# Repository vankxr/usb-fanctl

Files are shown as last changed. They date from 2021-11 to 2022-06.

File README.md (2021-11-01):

# USB Fan Controller
There are many USB fan controllers on sale, but none of them allow you to PWM 2-pin fans, as far as I am aware. This controller implements a compatible and widely supported USB serial port interface and allows you to control fans with it. It also supports 1-Wire sensors for temperature measurement.

## Authors

* **João Silva** - [vankxr](https://github.com/vankxr)

## License

The content of this repository is licensed under the [GNU General Public License v3.0](LICENSE).

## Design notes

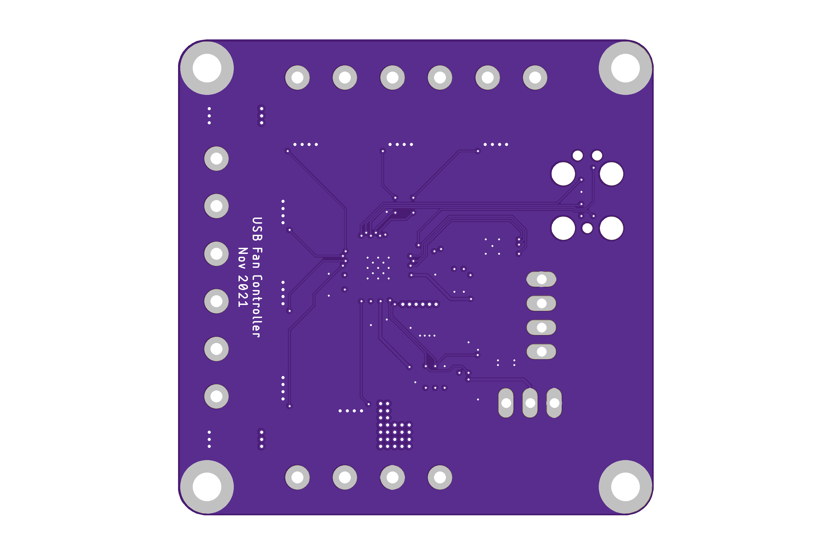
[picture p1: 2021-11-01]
pcb/usb-fanctl-bot.png

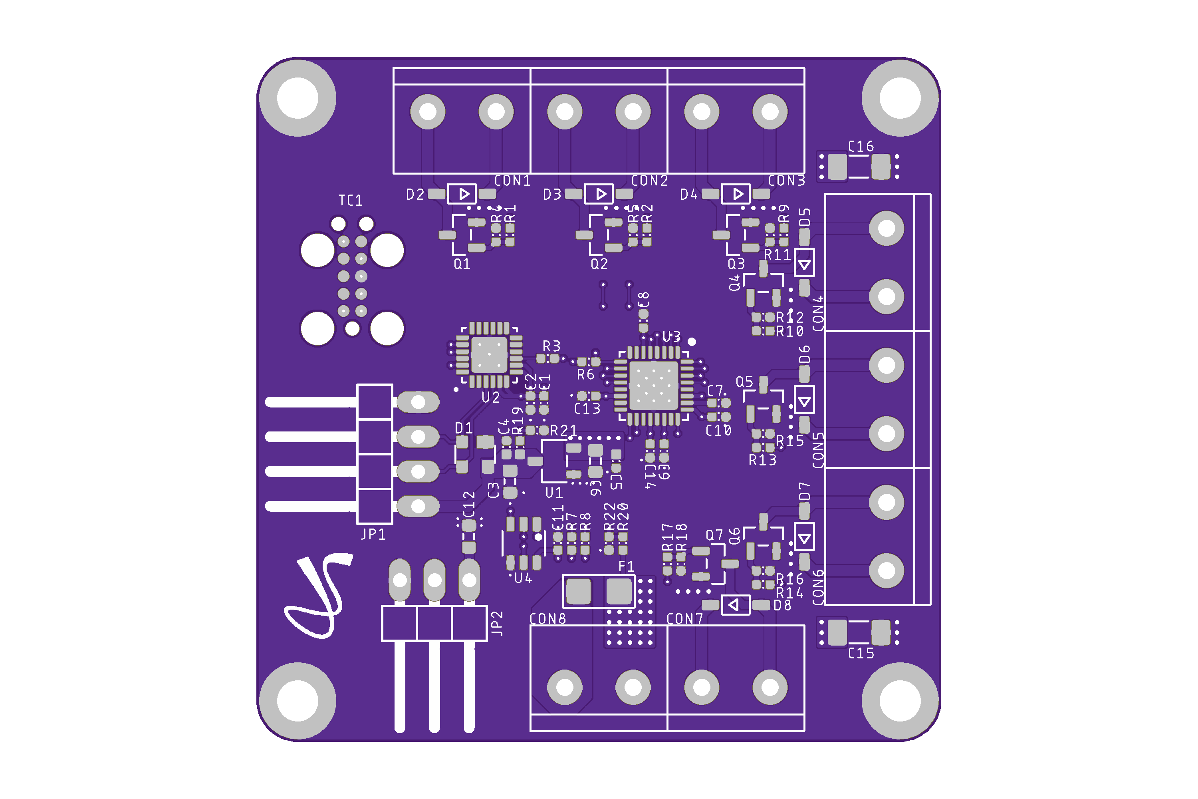
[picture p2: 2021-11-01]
pcb/usb-fanctl-top.png

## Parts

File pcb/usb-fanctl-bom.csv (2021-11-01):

Comment | Footprint | Designator
PTC 3A | PTC1206 | F1
100K Ohms | RES0402 | R20
100nF | CAP0402 | C1, C4, C5, C8, C9, C10, C11, C13, C14
10K Ohms | RES0402 | R4, R5, R6, R11, R12, R15, R16, R18, R19, R22
10uF | CAP0603 | C3, C6, C12
1K Ohms | RES0402 | R3, R7, R8
1uF | CAP0402 | C2, C7
22 Ohms | RES0402 | R1, R2, R9, R10, R13, R14, R17
22uF | CAP1206 | C15, C16
8.2K Ohms | RES0402 | R21
AO3400 | SOT23 | Q1, Q2, Q3, Q4, Q5, Q6, Q7
B0530W | SOD-123 | D2, D3, D4, D5, D6, D7, D8
CP2102N | QFN24 | U2
DS2484 | SOT23-6 | U4
EFM32PG1B100F256GM32 | QFN32_0.5P_JPG | U3
KF301-2P | KF301-2P | CON1, CON2, CON3, CON4, CON5, CON6, CON7, CON8
MCP1700-330 | SOT23 | U1
PINHD-1X3/90 | 1X03/90 | JP2
PINHD-1X4/90 | 1X04/90 | JP1
SP0503BAHT | SOT143 | D1

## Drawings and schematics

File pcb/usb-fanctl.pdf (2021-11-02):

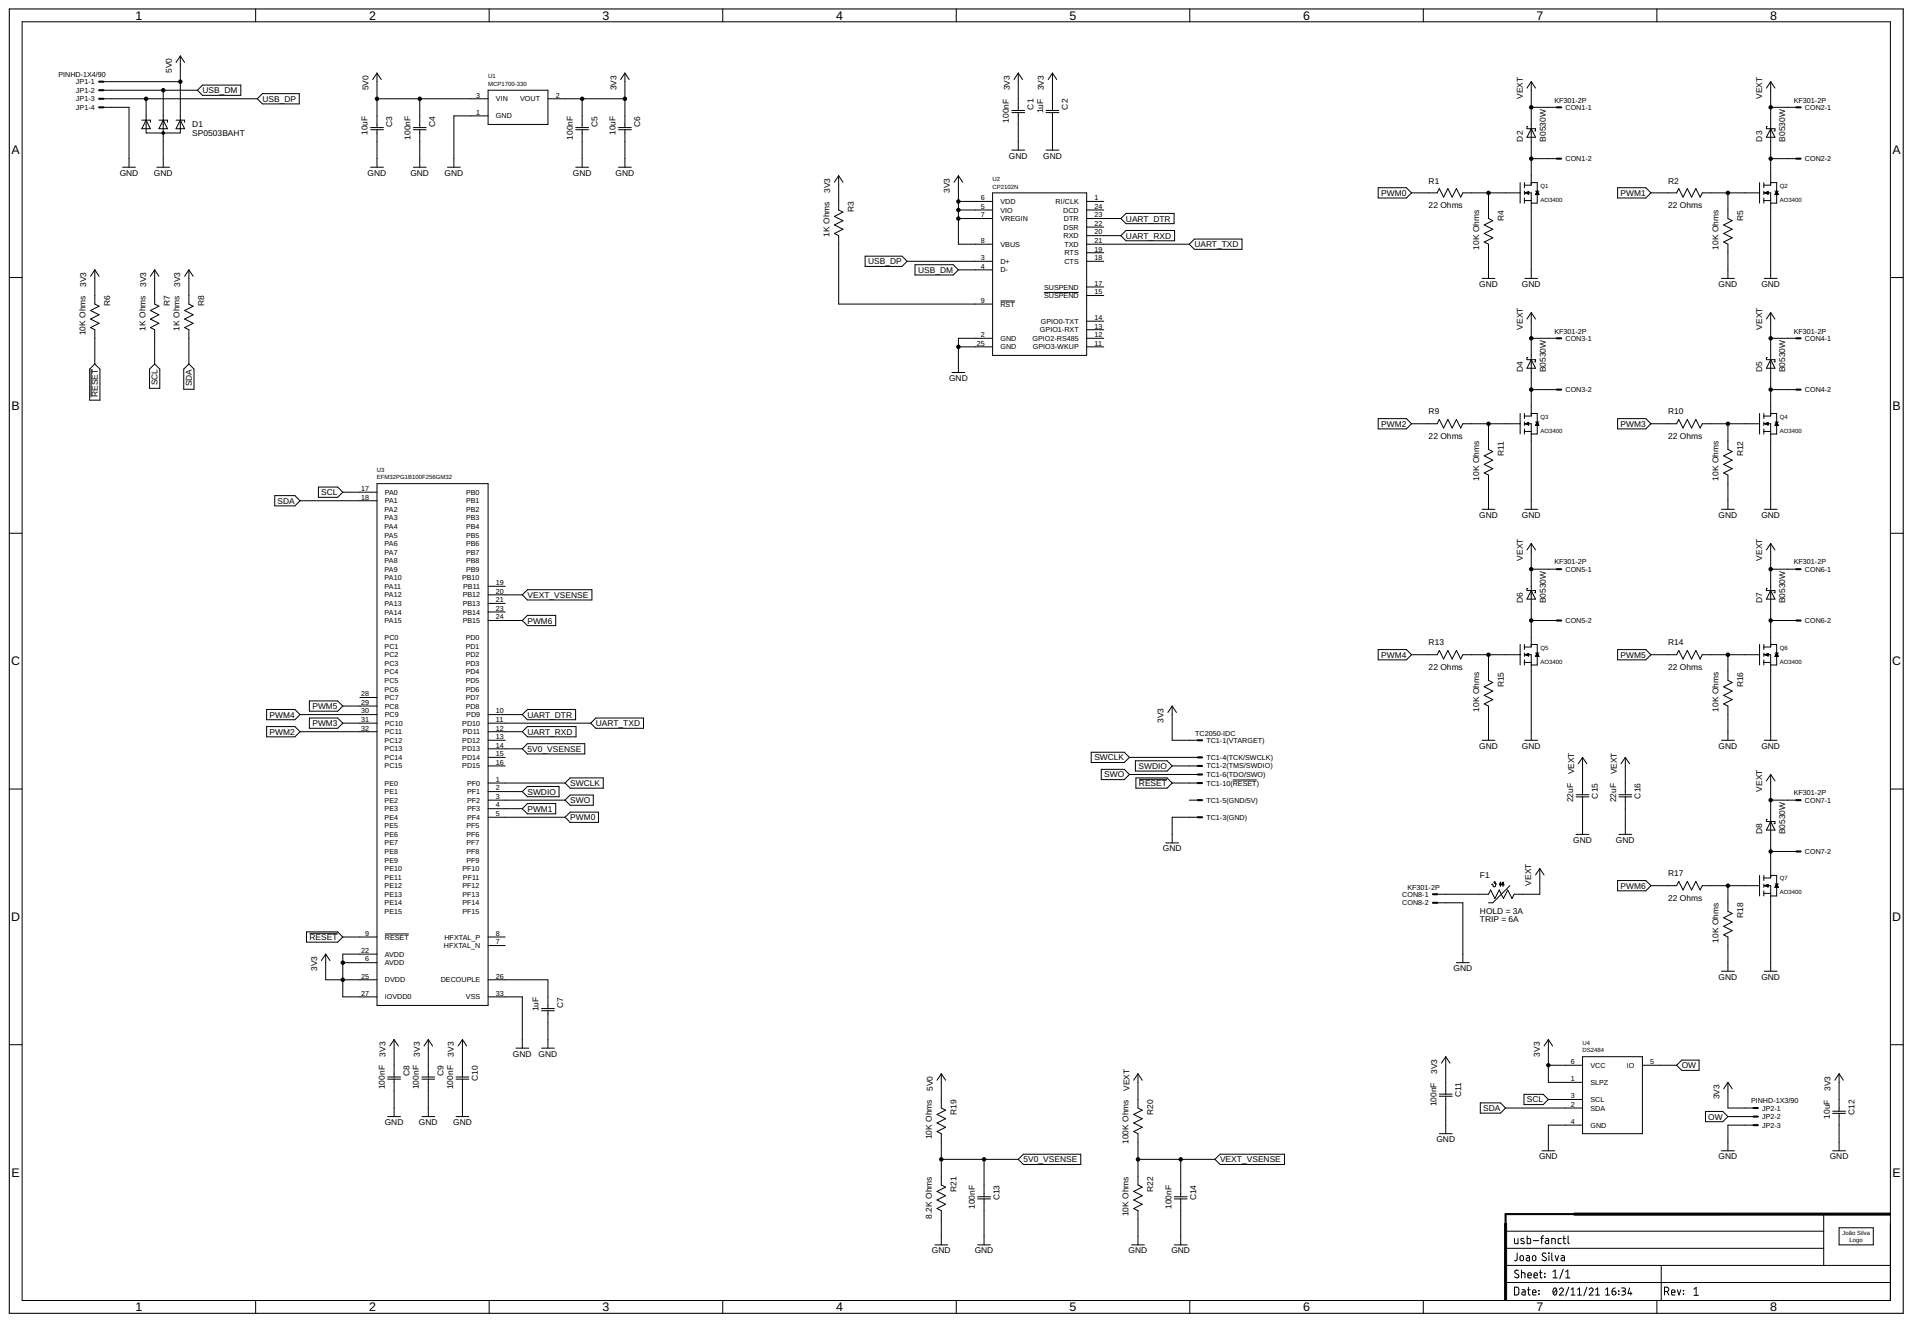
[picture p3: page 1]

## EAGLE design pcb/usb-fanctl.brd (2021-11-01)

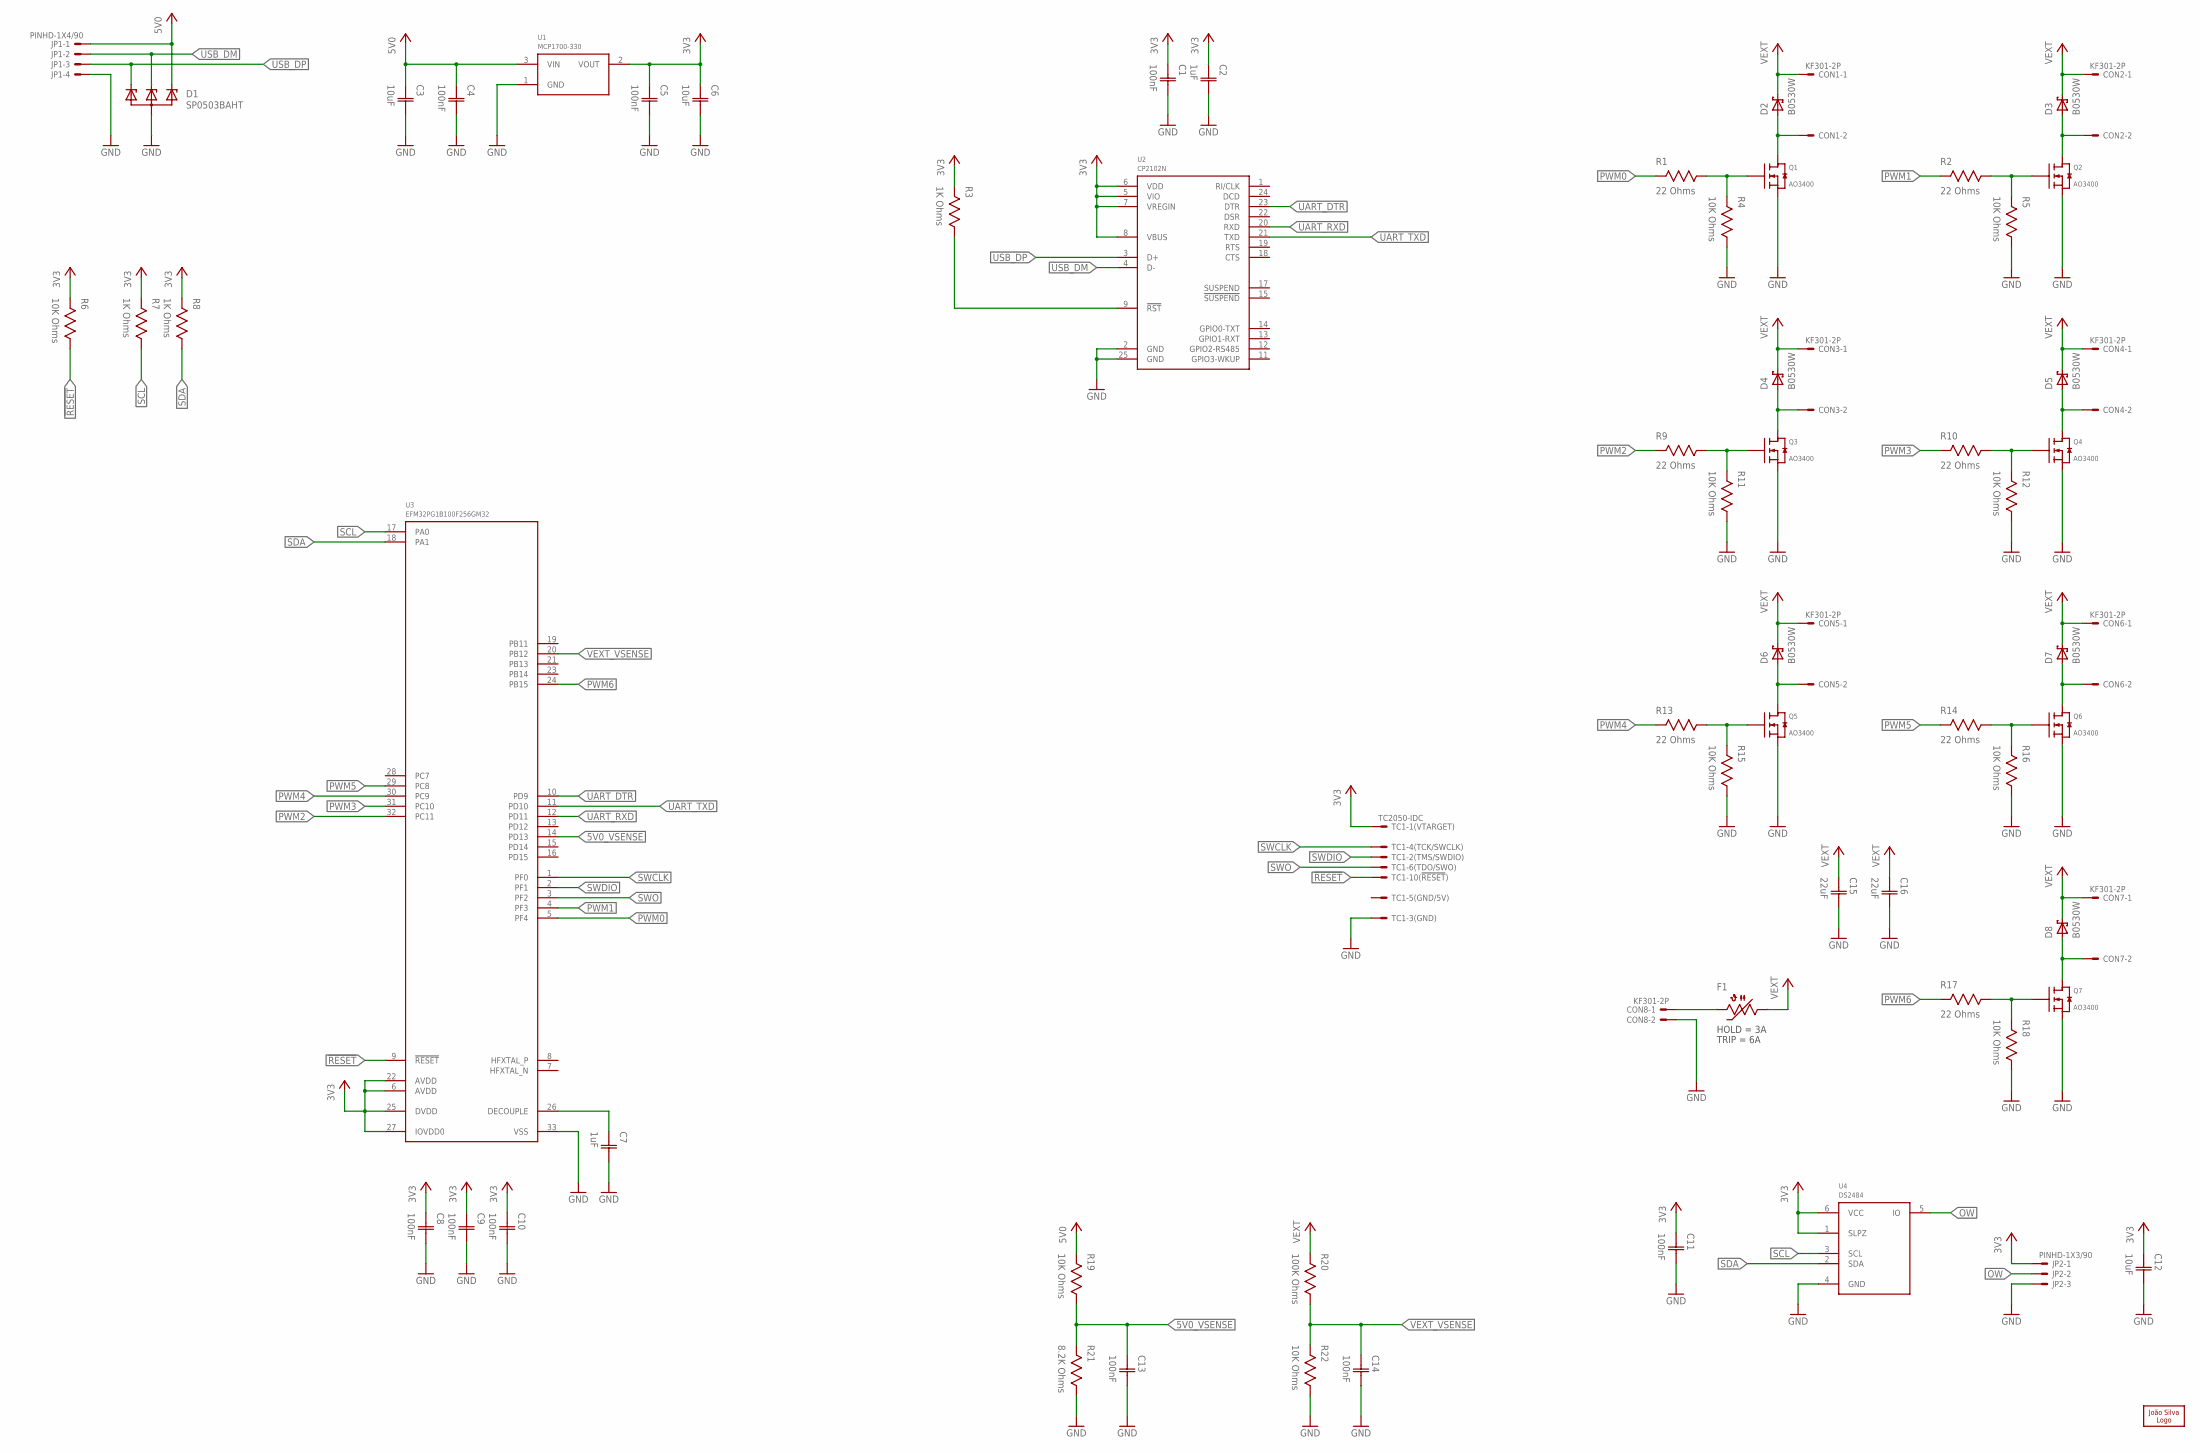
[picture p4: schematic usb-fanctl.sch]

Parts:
C1, C4, C5, C8, C9, C10, C11, C13, C14: 100nF; CAP0402
C2, C7: 1uF; CAP0402
C3, C6, C12: 10uF; CAP0603
C15, C16: 22uF; CAP1206
CON1, CON2, CON3, CON4, CON5, CON6, CON7, CON8: KF301-2P
D1: SP0503BAHT; SOT143
D2, D3, D4, D5, D6, D7, D8: B0530W; SOD-123
F1: PTC1206; 1206
JP1: PINHD-1X4/90; 1X04/90
JP2: PINHD-1X3/90; 1X03/90
LOGO1: JS-5MM; JS_5MM
Q1, Q2, Q3, Q4, Q5, Q6, Q7: AO3400; SOT23
R1, R2, R9, R10, R13, R14, R17: 22 Ohms; RES0402
R3, R7, R8: 1K Ohms; RES0402
R4, R5, R6, R11, R12, R15, R16, R18, R19, R22: 10K Ohms; RES0402
R20: 100K Ohms; RES0402
R21: 8.2K Ohms; RES0402
TC1: TC2050-IDC
U1: MCP1700-330; SOT23
U2: CP2102N; QFN24
U3: EFM32PG1B100F256GM32; QFN32_0.5P_JPG
U4: DS2484; SOT23-6

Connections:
3V3: C1.1 (C1), C2.1 (C1), C5.1 (C1), C6.1 (C1), C8.1 (C1), C9.1 (C1), C10.1 (C1), C11.1 (C1), C12.1 (C1), JP2.1, R3.2, R6.2, R7.2, R8.2, TC1.1, U1.2 (VOUT), U2.5 (VIO), U2.6 (VDD), U2.7 (VREGIN), U2.8 (VBUS), U3.6 (AVDD), U3.22 (AVDD), U3.25 (DVDD), U3.27 (IOVDD0), U4.1 (SLPZ), U4.6 (VCC)
5V0: C3.1 (C1), C4.1 (C1), D1.4 (C3), JP1.1, R19.2, U1.3 (VIN)
5V0_VSENSE: C13.1 (C1), R19.1, R21.2, U3.14 (PD13)
!RESET: R6.1, TC1.10, U3.9 (!RESET)
GND: C1.2 (C2), C2.2 (C2), C3.2 (C2), C4.2 (C2), C5.2 (C2), C6.2 (C2), C7.2 (C2), C8.2 (C2), C9.2 (C2), C10.2 (C2), C11.2 (C2), C12.2 (C2), C13.2 (C2), C14.2 (C2), C15.2 (C2), C16.2 (C2), CON8.2, D1.1 (A), JP1.4, JP2.3, Q1.2 (S), Q2.2 (S), Q3.2 (S), Q4.2 (S), Q5.2 (S), Q6.2 (S), Q7.2 (S), R4.1, R5.1, R11.1, R12.1, R15.1, R16.1, R18.1, R21.1, R22.1, TC1.3, U1.1 (GND), U2.2 (GND), U2.25 (GND), U3.33 (VSS), U4.4 (GND)
unnamed: Q2.1 (G), R2.1, R5.2
unnamed: CON2.2, D3.A, Q2.3 (D)
unnamed: Q4.1 (G), R10.1, R12.2
unnamed: CON4.2, D5.A, Q4.3 (D)
unnamed: Q6.1 (G), R14.1, R16.2
unnamed: CON6.2, D7.A, Q6.3 (D)
unnamed: Q7.1 (G), R17.1, R18.2
unnamed: CON7.2, D8.A, Q7.3 (D)
unnamed: Q1.1 (G), R1.1, R4.2
unnamed: CON1.2, D2.A, Q1.3 (D)
unnamed: Q3.1 (G), R9.1, R11.2
unnamed: CON3.2, D4.A, Q3.3 (D)
unnamed: Q5.1 (G), R13.1, R15.2
unnamed: CON5.2, D6.A, Q5.3 (D)
unnamed: C7.1 (C1), U3.26 (DECOUPLE)
unnamed: R3.1, U2.9 (!RST)
OW: JP2.2, U4.5 (IO)
PWM0: R1.2, U3.5 (PF4)
PWM1: R2.2, U3.4 (PF3)
PWM2: R9.2, U3.32 (PC11)
PWM3: R10.2, U3.31 (PC10)
PWM4: R13.2, U3.30 (PC9)
PWM5: R14.2, U3.29 (PC8)
PWM6: R17.2, U3.24 (PB15)
SCL: R7.1, U3.17 (PA0), U4.3 (SCL)
SDA: R8.1, U3.18 (PA1), U4.2 (SDA)
SWCLK: TC1.4, U3.1 (PF0)
SWDIO: TC1.2, U3.2 (PF1)
SWO: TC1.6, U3.3 (PF2)
UART_DTR: U2.23 (DTR), U3.10 (PD9)
UART_RXD: U2.20 (RXD), U3.12 (PD11)
UART_TXD: U2.21 (TXD), U3.11 (PD10)
USB_DM: D1.3 (C2), JP1.2, U2.4 (D-)
USB_DP: D1.2 (C1), JP1.3, U2.3 (D+)
VEXT: C15.1 (C1), C16.1 (C1), CON1.1, CON2.1, CON3.1, CON4.1, CON5.1, CON6.1, CON7.1, D2.C, D3.C, D4.C, D5.C, D6.C, D7.C, D8.C, F1.1, R20.2
VEXT_UNFUSED: CON8.1, F1.2
VEXT_VSENSE: C14.1 (C1), R20.1, R22.2, U3.20 (PB12)

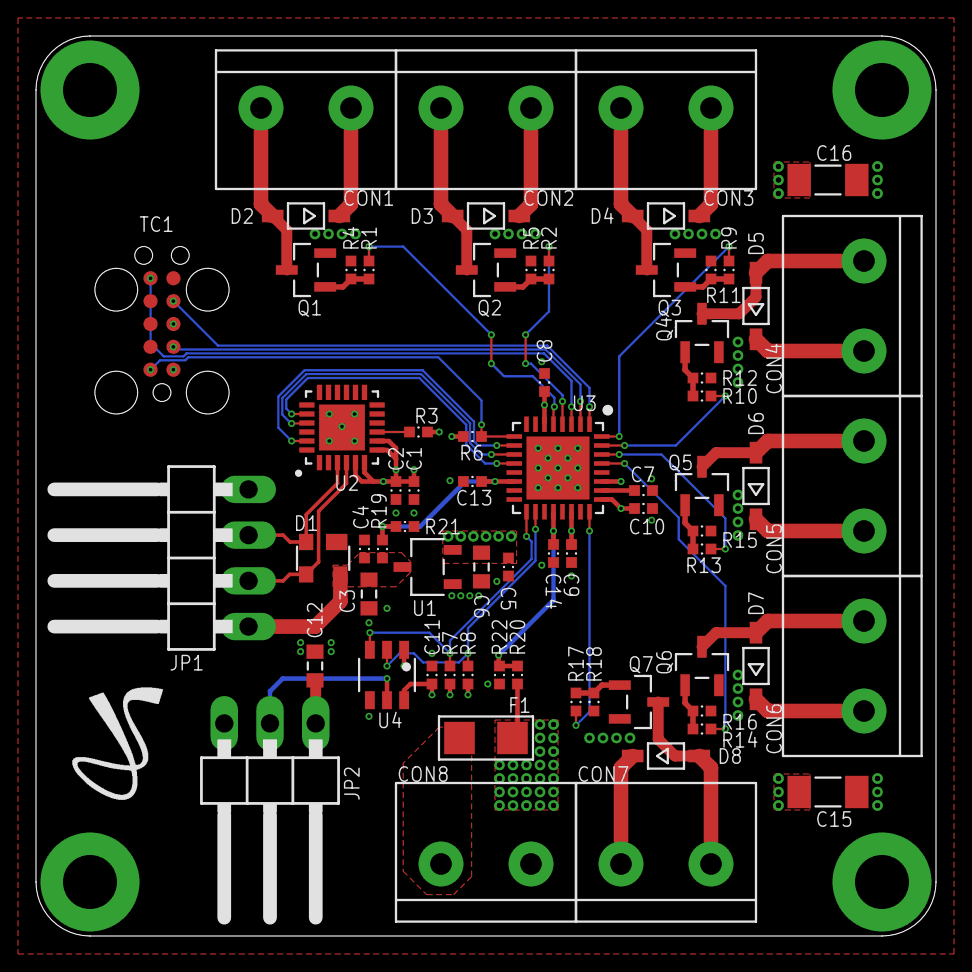
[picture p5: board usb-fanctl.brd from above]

Board: 4 copper layers, 50.0 x 50.0 mm, 70 parts (0 on the bottom side), 42 nets.

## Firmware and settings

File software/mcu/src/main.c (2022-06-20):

#include <em_device.h>
#include <stdlib.h>
#include <math.h>
#include "debug_macros.h"
#include "utils.h"
#include "nvic.h"
#include "atomic.h"
#include "systick.h"
#include "rmu.h"
#include "emu.h"
#include "cmu.h"
#include "gpio.h"
#include "dbg.h"
#include "msc.h"
#include "rtcc.h"
#include "adc.h"
#include "crc.h"
#include "usart.h"
#include "i2c.h"
#include "wdog.h"

// Structs
typedef struct __attribute__((__packed__))
{
    uint16_t usMagic;
    uint8_t ubCommand;
    uint8_t ubPayloadSize;
} usart_cmd_header_t;

typedef struct __attribute__((__packed__))
{
    uint8_t ubChannel;
    float fDutyCycle;
} usart_cmd_set_dc_t;
typedef struct __attribute__((__packed__))
{
    uint8_t ubChannel;
    float fDutyCycle;
} usart_cmd_get_dc_t;
typedef struct __attribute__((__packed__))
{
    float fFreq;
} usart_cmd_set_freq_t;
typedef struct __attribute__((__packed__))
{
    float fFreq;
} usart_cmd_get_freq_t;
typedef struct __attribute__((__packed__))
{
    uint8_t ubChannel;
    float fVoltage;
} usart_cmd_get_voltage_t;
typedef struct __attribute__((__packed__))
{
    uint8_t ubChannel;
    float fTemperature;
} usart_cmd_get_temp_t;
typedef struct __attribute__((__packed__))
{
    uint32_t ulUID[2];
} usart_cmd_get_uid_t;
typedef struct __attribute__((__packed__))
{
    uint16_t usVersion;
    char szDate[12];
    char szTime[9];
} usart_cmd_get_sw_info_t;

// Defines
#define TIMER_PWM_MIN_FREQ_HZ   500
#define TIMER_PWM_MAX_FREQ_HZ   1600000
#define TIMER_PWM_DEF_FREQ_HZ   25000

#define USART_HEADER_MAGIC      0xFAC7

#define USART_CMD_SET_DC        0x01
#define USART_CMD_GET_DC        0x02
#define USART_CMD_GET_VOLTAGE   0x03
#define USART_CMD_GET_TEMP      0x04
#define USART_CMD_SET_FREQ      0x05
#define USART_CMD_GET_FREQ      0x06
#define USART_CMD_ERROR         0xE0
#define USART_CMD_GET_UID       0xF0
#define USART_CMD_GET_SW_INFO   0xF1
#define USART_CMD_RESET_BL      0xFE
#define USART_CMD_RESET_APP     0xFF

#define USART_VOLTAGE_AVDD      0
#define USART_VOLTAGE_DVDD      1
#define USART_VOLTAGE_IOVDD     2
#define USART_VOLTAGE_CORE      3
#define USART_VOLTAGE_5V0       4
#define USART_VOLTAGE_VEXT      5

#define USART_TEMP_EMU          0
#define USART_TEMP_ADC          1

// Forward declarations
static void reset() __attribute__((noreturn));
static void sleep();

static uint32_t get_free_ram();

static void get_device_name(char *pszDeviceName, uint32_t ulDeviceNameSize);
static uint16_t get_device_revision();

static void wdog_warning_isr();

static void init_timers();
static void set_freq(float fFreq);
static float get_freq();
static void set_channel_dc(uint8_t ubChannel, float fDuty);
static float get_channel_dc(uint8_t ubChannel);

// Variables

// ISRs

// Functions
void reset()
{
    SCB->AIRCR = 0x05FA0000 | _VAL2FLD(SCB_AIRCR_SYSRESETREQ, 1);

    while(1);
}
void sleep()
{
    rtcc_set_alarm(rtcc_get_time() + 5);

    SCB->SCR |= SCB_SCR_SLEEPDEEP_Msk; // Configure Deep Sleep (EM2/3)

    ATOMIC_BLOCK(ATOMIC_RESTORESTATE)
    {
        IRQ_CLEAR(RTCC_IRQn);

        __DMB(); // Wait for all memory transactions to finish before memory access
        __DSB(); // Wait for all memory transactions to finish before executing instructions
        __ISB(); // Wait for all memory transactions to finish before fetching instructions
        __SEV(); // Set the event flag to ensure the next WFE will be a NOP
        __WFE(); // NOP and clear the event flag
        __WFE(); // Wait for event
        __NOP(); // Prevent debugger crashes

        cmu_init();
        cmu_update_clocks();
    }
}

uint32_t get_free_ram()
{
    ATOMIC_BLOCK(ATOMIC_RESTORESTATE)
    {
        extern void *_sbrk(int);

        void *pCurrentHeap = _sbrk(1);

        if(!pCurrentHeap)
            return 0;

        uint32_t ulFreeRAM = (uint32_t)__get_MSP() - (uint32_t)pCurrentHeap;

        _sbrk(-1);

        return ulFreeRAM;
    }
}

void get_device_name(char *pszDeviceName, uint32_t ulDeviceNameSize)
{
    uint8_t ubFamily = (DEVINFO->PART & _DEVINFO_PART_DEVICE_FAMILY_MASK) >> _DEVINFO_PART_DEVICE_FAMILY_SHIFT;
    const char* szFamily = "?";

    switch(ubFamily)
    {
        case 0x10: szFamily = "EFR32MG1P";  break;
        case 0x11: szFamily = "EFR32MG1B";  break;
        case 0x12: szFamily = "EFR32MG1V";  break;
        case 0x13: szFamily = "EFR32BG1P";  break;
        case 0x14: szFamily = "EFR32BG1B";  break;
        case 0x15: szFamily = "EFR32BG1V";  break;
        case 0x19: szFamily = "EFR32FG1P";  break;
        case 0x1A: szFamily = "EFR32FG1B";  break;
        case 0x1B: szFamily = "EFR32FG1V";  break;
        case 0x1C: szFamily = "EFR32MG12P"; break;
        case 0x1D: szFamily = "EFR32MG12B"; break;
        case 0x1E: szFamily = "EFR32MG12V"; break;
        case 0x1F: szFamily = "EFR32BG12P"; break;
        case 0x20: szFamily = "EFR32BG12B"; break;
        case 0x21: szFamily = "EFR32BG12V"; break;
        case 0x25: szFamily = "EFR32FG12P"; break;
        case 0x26: szFamily = "EFR32FG12B"; break;
        case 0x27: szFamily = "EFR32FG12V"; break;
        case 0x28: szFamily = "EFR32MG13P"; break;
        case 0x29: szFamily = "EFR32MG13B"; break;
        case 0x2A: szFamily = "EFR32MG13V"; break;
        case 0x2B: szFamily = "EFR32BG13P"; break;
        case 0x2C: szFamily = "EFR32BG13B"; break;
        case 0x2D: szFamily = "EFR32BG13V"; break;
        case 0x2E: szFamily = "EFR32ZG13P"; break;
        case 0x31: szFamily = "EFR32FG13P"; break;
        case 0x32: szFamily = "EFR32FG13B"; break;
        case 0x33: szFamily = "EFR32FG13V"; break;
        case 0x34: szFamily = "EFR32MG14P"; break;
        case 0x35: szFamily = "EFR32MG14B"; break;
        case 0x36: szFamily = "EFR32MG14V"; break;
        case 0x37: szFamily = "EFR32BG14P"; break;
        case 0x38: szFamily = "EFR32BG14B"; break;
        case 0x39: szFamily = "EFR32BG14V"; break;
        case 0x3A: szFamily = "EFR32ZG14P"; break;
        case 0x3D: szFamily = "EFR32FG14P"; break;
        case 0x3E: szFamily = "EFR32FG14B"; break;
        case 0x3F: szFamily = "EFR32FG14V"; break;
        case 0x47: szFamily = "EFM32G";     break;
        case 0x48: szFamily = "EFM32GG";    break;
        case 0x49: szFamily = "EFM32TG";    break;
        case 0x4A: szFamily = "EFM32LG";    break;
        case 0x4B: szFamily = "EFM32WG";    break;
        case 0x4C: szFamily = "EFM32ZG";    break;
        case 0x4D: szFamily = "EFM32HG";    break;
        case 0x51: szFamily = "EFM32PG1B";  break;
        case 0x53: szFamily = "EFM32JG1B";  break;
        case 0x55: szFamily = "EFM32PG12B"; break;
        case 0x57: szFamily = "EFM32JG12B"; break;
        case 0x64: szFamily = "EFM32GG11B"; break;
        case 0x67: szFamily = "EFM32TG11B"; break;
        case 0x6A: szFamily = "EFM32GG12B"; break;
        case 0x78: szFamily = "EZR32LG";    break;
        case 0x79: szFamily = "EZR32WG";    break;
        case 0x7A: szFamily = "EZR32HG";    break;
    }

    uint8_t ubPackage = (DEVINFO->MEMINFO & _DEVINFO_MEMINFO_PKGTYPE_MASK) >> _DEVINFO_MEMINFO_PKGTYPE_SHIFT;
    char cPackage = '?';

    if(ubPackage == 74)
        cPackage = '?';
    else if(ubPackage == 76)
        cPackage = 'L';
    else if(ubPackage == 77)
        cPackage = 'M';
    else if(ubPackage == 81)
        cPackage = 'Q';

    uint8_t ubTempGrade = (DEVINFO->MEMINFO & _DEVINFO_MEMINFO_TEMPGRADE_MASK) >> _DEVINFO_MEMINFO_TEMPGRADE_SHIFT;
    char cTempGrade = '?';

    if(ubTempGrade == 0)
        cTempGrade = 'G';
    else if(ubTempGrade == 1)
        cTempGrade = 'I';
    else if(ubTempGrade == 2)
        cTempGrade = '?';
    else if(ubTempGrade == 3)
        cTempGrade = '?';

    uint16_t usPartNumber = (DEVINFO->PART & _DEVINFO_PART_DEVICE_NUMBER_MASK) >> _DEVINFO_PART_DEVICE_NUMBER_SHIFT;
    uint8_t ubPinCount = (DEVINFO->MEMINFO & _DEVINFO_MEMINFO_PINCOUNT_MASK) >> _DEVINFO_MEMINFO_PINCOUNT_SHIFT;

    snprintf(pszDeviceName, ulDeviceNameSize, "%s%huF%hu%c%c%hhu", szFamily, usPartNumber, FLASH_SIZE >> 10, cTempGrade, cPackage, ubPinCount);
}
uint16_t get_device_revision()
{
    uint16_t usRevision;

    /* CHIP MAJOR bit [3:0]. */
    usRevision = ((ROMTABLE->PID0 & _ROMTABLE_PID0_REVMAJOR_MASK) >> _ROMTABLE_PID0_REVMAJOR_SHIFT) << 8;
    /* CHIP MINOR bit [7:4]. */
    usRevision |= ((ROMTABLE->PID2 & _ROMTABLE_PID2_REVMINORMSB_MASK) >> _ROMTABLE_PID2_REVMINORMSB_SHIFT) << 4;
    /* CHIP MINOR bit [3:0]. */
    usRevision |= (ROMTABLE->PID3 & _ROMTABLE_PID3_REVMINORLSB_MASK) >> _ROMTABLE_PID3_REVMINORLSB_SHIFT;

    return usRevision;
}

void wdog_warning_isr()
{
    DBGPRINTLN_CTX("Watchdog warning!");
}

void init_timers()
{
    // Timer 0
    cmu_hfper0_clock_gate(CMU_HFPERCLKEN0_TIMER0, 1);

    TIMER0->CTRL = TIMER_CTRL_RSSCOIST | TIMER_CTRL_PRESC_DIV1 | TIMER_CTRL_CLKSEL_PRESCHFPERCLK | TIMER_CTRL_FALLA_NONE | TIMER_CTRL_RISEA_NONE | TIMER_CTRL_MODE_UP;
    TIMER0->TOP = HFPER_CLOCK_FREQ / TIMER_PWM_DEF_FREQ_HZ - 1;
    TIMER0->CNT = 0x0000;

    TIMER0->CC[0].CTRL = TIMER_CC_CTRL_PRSCONF_LEVEL | TIMER_CC_CTRL_CUFOA_NONE | TIMER_CC_CTRL_COFOA_SET | TIMER_CC_CTRL_CMOA_CLEAR | TIMER_CC_CTRL_MODE_PWM;
    TIMER0->CC[0].CCV = 0x0000;

    TIMER0->CC[1].CTRL = TIMER_CC_CTRL_PRSCONF_LEVEL | TIMER_CC_CTRL_CUFOA_NONE | TIMER_CC_CTRL_COFOA_SET | TIMER_CC_CTRL_CMOA_CLEAR | TIMER_CC_CTRL_MODE_PWM;
    TIMER0->CC[1].CCV = 0x0000;

    TIMER0->CC[2].CTRL = TIMER_CC_CTRL_PRSCONF_LEVEL | TIMER_CC_CTRL_CUFOA_NONE | TIMER_CC_CTRL_COFOA_SET | TIMER_CC_CTRL_CMOA_CLEAR | TIMER_CC_CTRL_MODE_PWM;
    TIMER0->CC[2].CCV = 0x0000;

    TIMER0->ROUTELOC0 = TIMER_ROUTELOC0_CC0LOC_LOC28 | TIMER_ROUTELOC0_CC1LOC_LOC26 | TIMER_ROUTELOC0_CC2LOC_LOC14;
    TIMER0->ROUTEPEN |= TIMER_ROUTEPEN_CC0PEN | TIMER_ROUTEPEN_CC1PEN | TIMER_ROUTEPEN_CC2PEN;

    // Timer 1
    cmu_hfper0_clock_gate(CMU_HFPERCLKEN0_TIMER1, 1);

    TIMER1->CTRL = TIMER_CTRL_RSSCOIST | TIMER_CTRL_PRESC_DIV1 | TIMER_CTRL_CLKSEL_PRESCHFPERCLK | TIMER_CTRL_FALLA_NONE | TIMER_CTRL_RISEA_NONE | TIMER_CTRL_MODE_UP;
    TIMER1->TOP = HFPER_CLOCK_FREQ / TIMER_PWM_DEF_FREQ_HZ - 1;
    TIMER1->CNT = 0x0000;

    TIMER1->CC[0].CTRL = TIMER_CC_CTRL_PRSCONF_LEVEL | TIMER_CC_CTRL_CUFOA_NONE | TIMER_CC_CTRL_COFOA_SET | TIMER_CC_CTRL_CMOA_CLEAR | TIMER_CC_CTRL_MODE_PWM;
    TIMER1->CC[0].CCV = 0x0000;

    TIMER1->CC[1].CTRL = TIMER_CC_CTRL_PRSCONF_LEVEL | TIMER_CC_CTRL_CUFOA_NONE | TIMER_CC_CTRL_COFOA_SET | TIMER_CC_CTRL_CMOA_CLEAR | TIMER_CC_CTRL_MODE_PWM;
    TIMER1->CC[1].CCV = 0x0000;

    TIMER1->CC[2].CTRL = TIMER_CC_CTRL_PRSCONF_LEVEL | TIMER_CC_CTRL_CUFOA_NONE | TIMER_CC_CTRL_COFOA_SET | TIMER_CC_CTRL_CMOA_CLEAR | TIMER_CC_CTRL_MODE_PWM;
    TIMER1->CC[2].CCV = 0x0000;

    TIMER1->CC[3].CTRL = TIMER_CC_CTRL_PRSCONF_LEVEL | TIMER_CC_CTRL_CUFOA_NONE | TIMER_CC_CTRL_COFOA_SET | TIMER_CC_CTRL_CMOA_CLEAR | TIMER_CC_CTRL_MODE_PWM;
    TIMER1->CC[3].CCV = 0x0000;

    TIMER1->ROUTELOC0 = TIMER_ROUTELOC0_CC0LOC_LOC15 | TIMER_ROUTELOC0_CC1LOC_LOC13 | TIMER_ROUTELOC0_CC2LOC_LOC11 | TIMER_ROUTELOC0_CC3LOC_LOC7;
    TIMER1->ROUTEPEN |= TIMER_ROUTEPEN_CC0PEN | TIMER_ROUTEPEN_CC1PEN | TIMER_ROUTEPEN_CC2PEN | TIMER_ROUTEPEN_CC3PEN;

    // Start both timers
    TIMER0->CMD = TIMER_CMD_START;
    TIMER1->CMD = TIMER_CMD_START;
}
void set_freq(float fFreq)
{
    if(fFreq < TIMER_PWM_MIN_FREQ_HZ)
        return;

    if(fFreq > TIMER_PWM_MAX_FREQ_HZ)
        return;

    float fDutyBackup[7];

    for(uint8_t i = 0; i < 7; i++)
    {
        fDutyBackup[i] = get_channel_dc(i);

        set_channel_dc(i, 0.f);
    }

    TIMER0->TOPB = HFPER_CLOCK_FREQ / fFreq - 1;
    TIMER1->TOPB = HFPER_CLOCK_FREQ / fFreq - 1;

    for(uint8_t i = 0; i < 7; i++)
        set_channel_dc(i, fDutyBackup[i]);
}
float get_freq()
{
    return (float)HFPER_CLOCK_FREQ / (TIMER0->TOP + 1);
}
void set_channel_dc(uint8_t ubChannel, float fDuty)
{
    if(ubChannel > 6)
        return;

    if(fDuty < 0 || fDuty > 1)
        return;

    if(ubChannel > 2)
        TIMER1->CC[ubChannel - 3].CCVB = (uint16_t)(fDuty * TIMER1->TOP);
    else
        TIMER0->CC[ubChannel].CCVB = (uint16_t)(fDuty * TIMER0->TOP);
}
float get_channel_dc(uint8_t ubChannel)
{
    if(ubChannel > 6)
        return 0.f;

    if(ubChannel > 2)
        return (float)TIMER1->CC[ubChannel - 3].CCV / TIMER1->TOP;
    else
        return (float)TIMER0->CC[ubChannel].CCV / TIMER0->TOP;
}
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
int main()
{
    init_timers();

    while(1)
    {
        wdog_feed();

        static uint64_t ullLastUSARTChange = 0;
        static uint32_t ulLastUSARTAvailable = 0;

        if(usart0_available() != ulLastUSARTAvailable)
        {
            ulLastUSARTAvailable = usart0_available();
            ullLastUSARTChange = g_ullSystemTick;
        }

        if(ulLastUSARTAvailable != 0 && g_ullSystemTick - ullLastUSARTChange > 2000)
        {
            DBGPRINTLN_CTX("Clearing USART buffer...");

            usart0_flush();
        }

        if(usart0_available() >= sizeof(usart_cmd_header_t))
        {
            usart_cmd_header_t xHeader;

            DBGPRINTLN_CTX("Reading header...");
            usart0_read((uint8_t *)&xHeader, sizeof(usart_cmd_header_t));

            DBGPRINTLN_CTX("Header [M %04X] [C %02X] [S %02X]", xHeader.usMagic, xHeader.ubCommand, xHeader.ubPayloadSize);

            if(xHeader.usMagic != USART_HEADER_MAGIC)
            {
                DBGPRINTLN_CTX("Invalid magic!");

                continue;
            }

            switch(xHeader.ubCommand)
            {
                case USART_CMD_SET_DC:
                {
                    if(xHeader.ubPayloadSize != sizeof(usart_cmd_set_dc_t))
                    {
                        DBGPRINTLN_CTX("Invalid payload size!");

                        xHeader.ubCommand = USART_CMD_ERROR;
                        xHeader.ubPayloadSize = 0;
                        usart0_write((uint8_t *)&xHeader, sizeof(usart_cmd_header_t));

                        break;
                    }

                    if(usart0_available() < xHeader.ubPayloadSize)
                    {
                        DBGPRINTLN_CTX("Not enough data, waiting...");

                        uint64_t ullStartTick = g_ullSystemTick;

                        while(usart0_available() < xHeader.ubPayloadSize && g_ullSystemTick - ullStartTick <= 500);

                        if(usart0_available() < xHeader.ubPayloadSize)
                        {
                            DBGPRINTLN_CTX("Timed out waiting for payload!");

                            xHeader.ubCommand = USART_CMD_ERROR;
                            xHeader.ubPayloadSize = 0;
                            usart0_write((uint8_t *)&xHeader, sizeof(usart_cmd_header_t));

                            break;
                        }
                    }

                    usart_cmd_set_dc_t xPayload;

                    DBGPRINTLN_CTX("Reading payload...");
                    usart0_read((uint8_t *)&xPayload, xHeader.ubPayloadSize);

                    DBGPRINTLN_CTX("USART_CMD_SET_DC [C %hhu] [D %.6f]", xPayload.ubChannel, xPayload.fDutyCycle);

                    if(xPayload.ubChannel > 6)
                    {
                        DBGPRINTLN_CTX("Invalid channel!");

                        xHeader.ubCommand = USART_CMD_ERROR;
                        xHeader.ubPayloadSize = 0;
                        usart0_write((uint8_t *)&xHeader, sizeof(usart_cmd_header_t));

                        break;
                    }

                    if(xPayload.fDutyCycle < 0.0f || xPayload.fDutyCycle > 1.0f)
                    {
                        DBGPRINTLN_CTX("Invalid duty cycle!");

                        xHeader.ubCommand = USART_CMD_ERROR;
                        xHeader.ubPayloadSize = 0;
                        usart0_write((uint8_t *)&xHeader, sizeof(usart_cmd_header_t));

                        break;
                    }

                    set_channel_dc(xPayload.ubChannel, xPayload.fDutyCycle);

                    xHeader.ubPayloadSize = 0;
                    usart0_write((uint8_t *)&xHeader, sizeof(usart_cmd_header_t));
                }
                break;
                case USART_CMD_GET_DC:
                {
                    if(xHeader.ubPayloadSize != sizeof(usart_cmd_get_dc_t))
                    {
                        DBGPRINTLN_CTX("Invalid payload size!");

                        xHeader.ubCommand = USART_CMD_ERROR;
                        xHeader.ubPayloadSize = 0;
                        usart0_write((uint8_t *)&xHeader, sizeof(usart_cmd_header_t));

                        break;
                    }

                    if(usart0_available() < xHeader.ubPayloadSize)
                    {
                        DBGPRINTLN_CTX("Not enough data, waiting...");

                        uint64_t ullStartTick = g_ullSystemTick;

                        while(usart0_available() < xHeader.ubPayloadSize && g_ullSystemTick - ullStartTick <= 500);

                        if(usart0_available() < xHeader.ubPayloadSize)
                        {
                            DBGPRINTLN_CTX("Timed out waiting for payload!");

                            xHeader.ubCommand = USART_CMD_ERROR;
                            xHeader.ubPayloadSize = 0;
                            usart0_write((uint8_t *)&xHeader, sizeof(usart_cmd_header_t));

                            break;
                        }
                    }

                    usart_cmd_get_dc_t xPayload;

                    DBGPRINTLN_CTX("Reading payload...");
                    usart0_read((uint8_t *)&xPayload, xHeader.ubPayloadSize);

                    DBGPRINTLN_CTX("USART_CMD_GET_DC [C %hhu]", xPayload.ubChannel);

                    if(xPayload.ubChannel > 6)
                    {
                        DBGPRINTLN_CTX("Invalid channel!");

                        xHeader.ubCommand = USART_CMD_ERROR;
                        xHeader.ubPayloadSize = 0;
                        usart0_write((uint8_t *)&xHeader, sizeof(usart_cmd_header_t));

                        break;
                    }

                    xPayload.fDutyCycle = get_channel_dc(xPayload.ubChannel);

                    usart0_write((uint8_t *)&xHeader, sizeof(usart_cmd_header_t));
                    usart0_write((uint8_t *)&xPayload, sizeof(usart_cmd_get_dc_t));
                }
                break;
                case USART_CMD_GET_VOLTAGE:
                {
                    if(xHeader.ubPayloadSize != sizeof(usart_cmd_get_voltage_t))
                    {
                        DBGPRINTLN_CTX("Invalid payload size!");

                        xHeader.ubCommand = USART_CMD_ERROR;
                        xHeader.ubPayloadSize = 0;
                        usart0_write((uint8_t *)&xHeader, sizeof(usart_cmd_header_t));

                        break;
                    }

                    if(usart0_available() < xHeader.ubPayloadSize)
                    {
                        DBGPRINTLN_CTX("Not enough data, waiting...");

                        uint64_t ullStartTick = g_ullSystemTick;

                        while(usart0_available() < xHeader.ubPayloadSize && g_ullSystemTick - ullStartTick <= 500);

                        if(usart0_available() < xHeader.ubPayloadSize)
                        {
                            DBGPRINTLN_CTX("Timed out waiting for payload!");

                            xHeader.ubCommand = USART_CMD_ERROR;
                            xHeader.ubPayloadSize = 0;
                            usart0_write((uint8_t *)&xHeader, sizeof(usart_cmd_header_t));

                            break;
                        }
                    }

                    usart_cmd_get_voltage_t xPayload;

                    DBGPRINTLN_CTX("Reading payload...");
                    usart0_read((uint8_t *)&xPayload, xHeader.ubPayloadSize);

                    DBGPRINTLN_CTX("USART_CMD_GET_VOLTAGE [C %hhu]", xPayload.ubChannel);

                    switch(xPayload.ubChannel)
                    {
                        case USART_VOLTAGE_AVDD:
                        {
                            xPayload.fVoltage = adc_get_avdd();

                            usart0_write((uint8_t *)&xHeader, sizeof(usart_cmd_header_t));
                            usart0_write((uint8_t *)&xPayload, sizeof(usart_cmd_get_voltage_t));
                        }
                        break;
                        case USART_VOLTAGE_DVDD:
                        {
                            xPayload.fVoltage = adc_get_dvdd();

                            usart0_write((uint8_t *)&xHeader, sizeof(usart_cmd_header_t));
                            usart0_write((uint8_t *)&xPayload, sizeof(usart_cmd_get_voltage_t));
                        }
                        break;
                        case USART_VOLTAGE_IOVDD:
                        {
                            xPayload.fVoltage = adc_get_iovdd();
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

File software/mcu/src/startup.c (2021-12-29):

#include <em_device.h>

extern void _estack(); // Not really a function, just to be compatible with array later

extern uint32_t _svect; // ISR Vectors
extern uint32_t _evect;

extern uint32_t _stext; // Main program
extern uint32_t _etext;

extern uint32_t _siiram0; // RAM code source
extern uint32_t _siram0; // RAM code destination
extern uint32_t _eiram0;

extern uint32_t _siiram1; // RAMH code source
extern uint32_t _siram1; // RAMH code destination
extern uint32_t _eiram1;

extern uint32_t _sidata; // Data source
extern uint32_t _sdata; // Data destination
extern uint32_t _edata;

extern uint32_t _sbss; // BSS destination
extern uint32_t _ebss;

extern uint32_t _end;


void _default_isr()
{
    while(1);
}

void __attribute__ ((weak)) __libc_init_array()
{

}

extern int init();
extern int main();

#define DEFAULT_ISR "_default_isr"

void _reset_isr()
{
    volatile uint32_t *src, *dst;

    src = &_siiram0;
    dst = &_siram0;

    while (dst < &_eiram0) // Copy RAM code
        *(dst++) = *(src++);

    src = &_siiram1;
    dst = &_siram1;

    while (dst < &_eiram1) // Copy RAMH code
        *(dst++) = *(src++);

    src = &_sidata;
    dst = &_sdata;

    while (dst < &_edata) // Copy data
        *(dst++) = *(src++);

    src = 0;
    dst = &_sbss;

    while (dst < &_ebss) // Zero BSS
        *(dst++) = 0;

    __libc_init_array();

    SCB->VTOR = (uint32_t)&_svect; // ISR Vectors offset
    SCB->AIRCR = 0x05FA0000 | (5 << 8); // Interrupt priority - 2 bits Group, 1 bit Sub-group
    SCB->SHCSR = SCB_SHCSR_USGFAULTENA_Msk | SCB_SHCSR_BUSFAULTENA_Msk | SCB_SHCSR_MEMFAULTENA_Msk; // Enable separate fault handlers
    SCB->CCR |= SCB_CCR_DIV_0_TRP_Msk; // Enable division by zero faults
    SCB->CPACR |= 0xF << 20; // Enable CP10 & CP11 (FPU) in priv. and non priv. mode

    init();
    main();

    __disable_irq();
    while(1);
}

void _nmi_isr()                           __attribute__ ((weak,  alias (DEFAULT_ISR)));
void _hardfault_isr()                     __attribute__ ((weak,  alias (DEFAULT_ISR)));
void _memmanage_isr()                     __attribute__ ((weak,  alias (DEFAULT_ISR)));
void _busfault_isr()                      __attribute__ ((weak,  alias (DEFAULT_ISR)));
void _usagefault_isr()                    __attribute__ ((weak,  alias (DEFAULT_ISR)));
void _svc_isr()                           __attribute__ ((weak,  alias (DEFAULT_ISR)));
void _debugmon_isr()                      __attribute__ ((weak,  alias (DEFAULT_ISR)));
void _pendsv_isr()                        __attribute__ ((weak,  alias (DEFAULT_ISR)));
void _systick_isr()                       __attribute__ ((weak,  alias (DEFAULT_ISR)));
void _emu_isr()                           __attribute__ ((weak,  alias (DEFAULT_ISR)));
void _wdog0_isr()                         __attribute__ ((weak,  alias (DEFAULT_ISR)));
void _ldma_isr()                          __attribute__ ((weak,  alias (DEFAULT_ISR)));
void _gpio_even_isr()                     __attribute__ ((weak,  alias (DEFAULT_ISR)));
void _timer0_isr()                        __attribute__ ((weak,  alias (DEFAULT_ISR)));
void _usart0_rx_isr()                     __attribute__ ((weak,  alias (DEFAULT_ISR)));
void _usart0_tx_isr()                     __attribute__ ((weak,  alias (DEFAULT_ISR)));
void _acmp0_1_isr()                       __attribute__ ((weak,  alias (DEFAULT_ISR)));
void _adc0_isr()                          __attribute__ ((weak,  alias (DEFAULT_ISR)));
void _idac0_isr()                         __attribute__ ((weak,  alias (DEFAULT_ISR)));
void _i2c0_isr()                          __attribute__ ((weak,  alias (DEFAULT_ISR)));
void _gpio_odd_isr()                      __attribute__ ((weak,  alias (DEFAULT_ISR)));
void _timer1_isr()                        __attribute__ ((weak,  alias (DEFAULT_ISR)));
void _usart1_rx_isr()                     __attribute__ ((weak,  alias (DEFAULT_ISR)));
void _usart1_tx_isr()                     __attribute__ ((weak,  alias (DEFAULT_ISR)));
void _leuart0_isr()                       __attribute__ ((weak,  alias (DEFAULT_ISR)));
void _pcnt0_isr()                         __attribute__ ((weak,  alias (DEFAULT_ISR)));
void _cmu_isr()                           __attribute__ ((weak,  alias (DEFAULT_ISR)));
void _msc_isr()                           __attribute__ ((weak,  alias (DEFAULT_ISR)));
void _crypto_isr()                       __attribute__ ((weak,  alias (DEFAULT_ISR)));
void _letimer0_isr()                      __attribute__ ((weak,  alias (DEFAULT_ISR)));
void _rtcc_isr()                          __attribute__ ((weak,  alias (DEFAULT_ISR)));
void _cryotimer_isr()                     __attribute__ ((weak,  alias (DEFAULT_ISR)));
void _fpueh_isr()                         __attribute__ ((weak,  alias (DEFAULT_ISR)));

__attribute__ ((section(".isr_vector"))) void (* const g_pfnVectors[])() = {
    _estack,
    _reset_isr,
    _nmi_isr,
    _hardfault_isr,
    _memmanage_isr,
    _busfault_isr,
    _usagefault_isr,
    0,
    0,
    0,
    0,
    _svc_isr,
    _debugmon_isr,
    0,
    _pendsv_isr,
    _systick_isr,
    _emu_isr,
    0,
    _wdog0_isr,
    0,
    0,
    0,
    0,
    0,
    _ldma_isr,
    _gpio_even_isr,
    _timer0_isr,
    _usart0_rx_isr,
    _usart0_tx_isr,
    _acmp0_1_isr,
    _adc0_isr,
    _idac0_isr,
    _i2c0_isr,
    _gpio_odd_isr,
    _timer1_isr,
    _usart1_rx_isr,
    _usart1_tx_isr,
    _leuart0_isr,
    _pcnt0_isr,
    _cmu_isr,
    _msc_isr,
    _crypto_isr,
    _letimer0_isr,
    0,
    0,
    _rtcc_isr,
    0,
    _cryotimer_isr,
    0,
    _fpueh_isr
};

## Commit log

2021-11-01 Add PCB files
    [usb-fanctl.brd, usb-fanctl.sch]
2021-11-01 Add production files
    [usb-fanctl-bom.csv, usb-fanctl-pnp.csv, usb-fanctl.brd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]
2021-11-02 Fix schematic sheet attributes not showing
    [usb-fanctl.sch]
